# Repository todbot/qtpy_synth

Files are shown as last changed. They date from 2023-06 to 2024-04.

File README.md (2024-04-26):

# qtpy_synth

A simple [QTPy RP2040](https://learn.adafruit.com/adafruit-qt-py-2040/overview)-based
synth to experiment with [`synthio`](https://github.com/todbot/circuitpython-synthio-tricks).

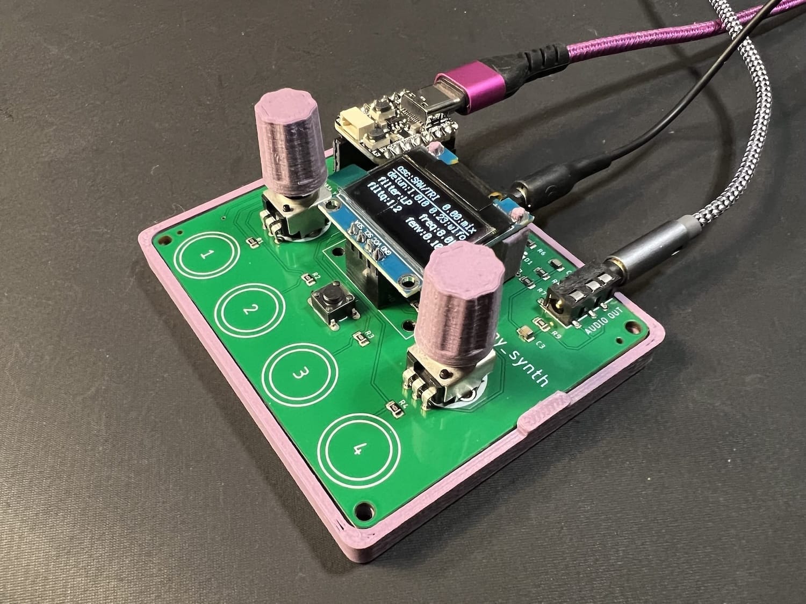
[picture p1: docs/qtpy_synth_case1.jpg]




### Features
 - Mono audio output circuit, converting PWM to audio, as per [RP2040 design guidelines](https://datasheets.raspberrypi.com/rp2040/hardware-design-with-rp2040.pdf#page=24)
 - Optoisolated MIDI Input via [MIDI TRS-A 3.5mm jack](https://www.perfectcircuit.com/make-noise-0-coast-midi-cable.html)
 - Two pots for controlling parameters
 - One switch for controlling parameters
 - Four capsense touch buttons for synth triggering
 - USB MIDI in/out of course too

### Software
Some programs written specifically for this board:

- [hwtest](./circuitpython/hwtest/code.py) - test out the hardware with a simple synth

- [simpletouchsynth](./circuitpython/simpletouchsynth) - play with filters using touch sensors. Uses intial cut at a "qtpy_synth" hardware library.

- [dronesynth](./circuitpython/dronesynth) - 8-oscillator drone synth

- [wavesynth](./circuitpython/wavesynth) - larger general two-osc synth that can also do wave-mixing and wavetables. Has many rough edges but can sound great!
  - early video demo:
  
    Wavetable synth w/ CircuitPython synthio on QTPy RP2040 (https://www.youtube.com/watch?v=4hgDi6MNfsI)]
  - another video demo:
  
    More Wavetable synth w/ CircuitPython synthio on QTPy RP2040 (https://www.youtube.com/watch?v=80yjwxscnnA)]

#### See also:
- https://github.com/todbot/circuitpython-synthio-tricks
  - Contains [many other synthio examples](https://github.com/todbot/circuitpython-synthio-tricks/tree/main/examples) that can work with this synth with minimal changes

### Building it

The [Tindie version is a partially-assembled PCB](https://www.tindie.com/products/todbot/qtpy_synth/). 

The completely assembled SMD sections of the board are:

* audio output circuit
* TRS MIDI input circuit

The parts you need to add are:

* [QTPy RP2040](https://www.adafruit.com/product/4900)
* 0.91" [I2C OLED display](https://amzn.to/3KDmy73) (w/ pins in Gnd/Vcc/SCL/SDA order)
* Two 10k potentiometers, 9mm  ([example pots](https://amzn.to/3DYYJm5)) and [knobs](https://amzn.to/3QAkSyR)
* One tact switch, 6mm ([example switch](https://amzn.to/47nJaSN))
* Headers and sockets to mount QTPy & display, to taste
  * [This male & female header kit looks pretty good](https://amzn.to/3qqbtiO),
    as I prefer to put female headers on the PCB and male headers on the QTPy and OLED display.
    You may need to trim down your headers to be the right size.
* Feet. I like M2.5 nylon standoffs  (e.g. [M2.5 standoff asst kit](https://amzn.to/45qVjFb))
  but feel free to do what you like, including making an enclosure!
* Or [3d-print a simple case](https://www.printables.com/model/757087-case-for-qtpy_synth-circuitpython-synthesizer) for it! I also like these [3d-printed knobs](https://www.thingiverse.com/thing:5759656)

### Pins used

The board uses all of the QTPy RP2040 pins:

* `board.A0` - left knob
* `board.A1` - right knob
* `board.TX` - middle button
* `board.RX` - TRS UART MIDI in
* `board.MOSI` - PWM Audio Out
* `board.SCL` & `board.SDA` - I2C bus for OLED display
* `board.A3`, `board.A2`, `board.MISO`, `board.SCK`,  -- touch pads 1,2,3,4

For more details see [`hwtest/code.py`](https://github.com/todbot/qtpy_synth/tree/main/circuitpython/hwtest/code.py).

### Schematic

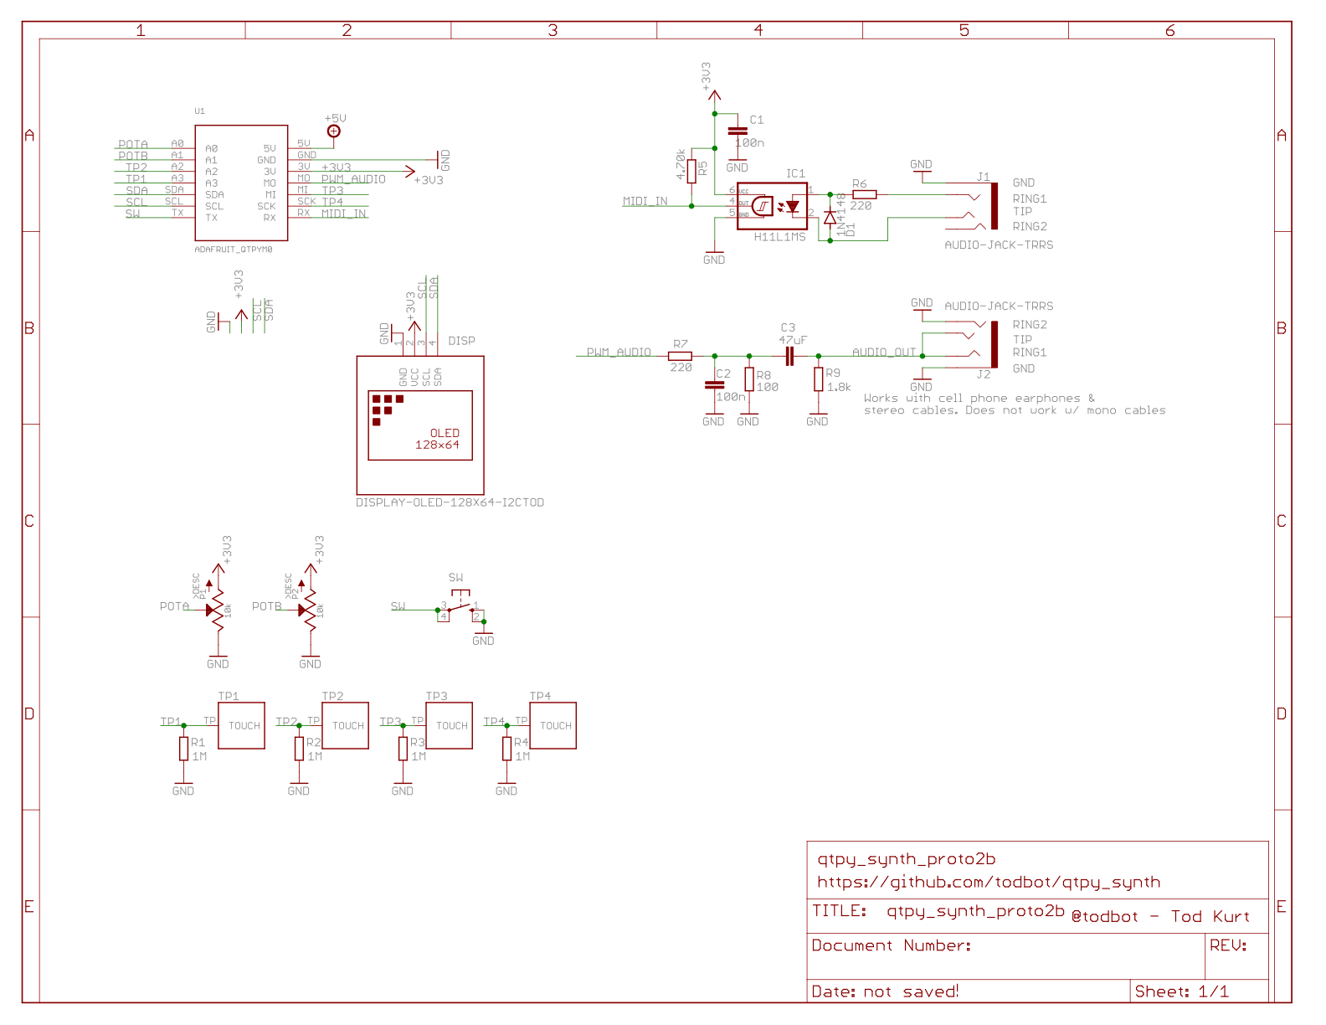
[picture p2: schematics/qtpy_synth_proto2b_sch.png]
[](./schematics/qtpy_synth_proto2b_sch.pdf)

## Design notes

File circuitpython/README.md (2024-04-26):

qtpy_synth circuitpython
========================

This is a collection of example synths to run on the qtpy_synth board.

These examples include:

- "[hwtest](./hwtest)" -- check that all hardware parts work
- "[simpletouchsynth](./simpletouchsynth)" -- very simple single-patch synth with adjustable filter
- "[wavesynth](./wavesynth)" -- wavetable synthesizer with GUI and wavetable selection

### Running the examples:

To run these examples:

1. Copy the contents of the `lib` here directory to CIRCUITPY/lib
2. Copy everything in example synth's directory to the CIRCUITPY drive 
     (e.g. `code.py` file and any other files)
3. Install external libraries. They are listed in `requirements.txt`.
    The easiest way to install them is with `circup` on the commandline:
    ```sh
    circup install -r requirements.txt
    ```

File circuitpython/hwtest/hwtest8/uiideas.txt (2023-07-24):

#
#
# UI Ideas:
#  - touch buttons
#    - press to trigger note
#    - hold to enable setting of button params, edit with potA, potB, sw
#      - what about holding multiple  (maybe do not allow)
#    - press hard for filter mod?
#  - pots
#    - if no button press, changes global param, like filter, res
#
#  - knob UI sets:
#
#    param sets
#    1. filter type + filter freq
#    2. osc detune + filter res
#    3. wave select (as below) + wave_mix
#    4. atk / rls
#
#    or:
#    1. wave select (saw/tri/wtb + fname) + wave_mix
#    2. osc detune + wave_mix_lfo
#    3a. filter type + filter freq
#    3b. filter res + filter_env_amount
#    4. atk / rls
#
#    x. osc/wtb e | wave saw/squ/tri
#       - waveA squ/tri/saw + wave_mix
#         (turning A goes : Asaw->None, Asaw->Bsqu, Asaw->Btri, Asqu->BNon, Asqu->Btri, Atri->None
#
#    x turn knobA choices:
#       - osc: A saw / B tri
#         osc: A saw / B squ
#         osc: A saw / B sin
#         osc: A squ / B tri
#         osc: A squ / B tri
#         wtb: wave filename1
#         wtb: wave filename2
#         wtb: wave filename3
#         wtb: wave filename4
#
#
#    x. wavetable + wave_mix_lfo
#
#    4. atk time / rls time
#
#  - sw
#    - toggles currently changeable pot params
#      - param set 1: freq & resonance
#      - param set 2: freq type (LP,HP,BP,BN) & osc detune spread
#      - param set 3: attack & release times
#      - param set 4: LFO1 rate & depth
#
# Arpeggiator?
#

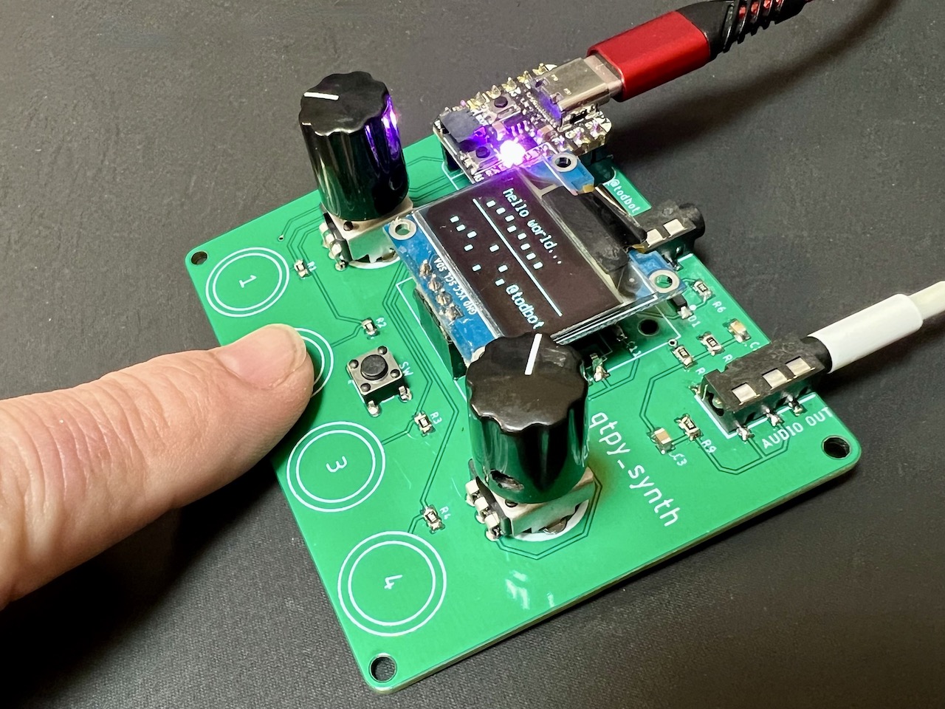
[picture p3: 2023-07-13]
docs/qtpy_synth_proto2a.jpg

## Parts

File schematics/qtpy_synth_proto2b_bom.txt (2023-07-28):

Qty	Value	Device	Package	Parts	Description	LCSC	MF MPN
1		10-XX	B3F-10XX	SW	OMRON SWITCH		B3F-1000
1	1.8k	R-EU_R0805	R0805	R9	"RESISTOR, European symbol"		
1	100	R-EU_R0805	R0805	R8	"RESISTOR, European symbol"		
2	100n	C-EUC0805	C0805	"C1, C2"	"CAPACITOR, European symbol"		
2	10k	POTZEPHPOT_BIGKNOB	OG-POTS_ALPS_POT_VERTICAL_WITHBIGKNOB	"P1, P2"			
4	1M	R-EU_R0805	R0805	"R1, R2, R3, R4"	"RESISTOR, European symbol"		
1	1N4148	DIODE-SOD123	SOD123	D1	DIODE		
2	220	R-EU_R0805	R0805	"R6, R7"	"RESISTOR, European symbol"		
1	4.70k	R-EU_R0805	R0805	R5	"RESISTOR, European symbol"		
1	47uF	C-EUC0805	C0805	C3	"CAPACITOR, European symbol"		
1	ADAFRUIT_QTPYM0	ADAFRUIT_QTPYM0	ADAFRUIT_QTPY_M0	U1			
2	AUDIO-JACK-TRRS	AUDIO-JACK-TRRS	PJ-320D_SPARKFUN	"J1, J2"		C431535	PJ-320D
1	DISPLAY-OLED-128X64-I2CTOD	DISPLAY-OLED-128X64-I2CTOD	DISPLAY-OLED-128X64-I2C-TOD	DISP	128x64 Dot Matrix OLED Module	based on SSD1306 chip	
1	H11L1MS	H11L1MS	DIL6-SMD	IC1	6-Pin DIP Optocoupler	C78589

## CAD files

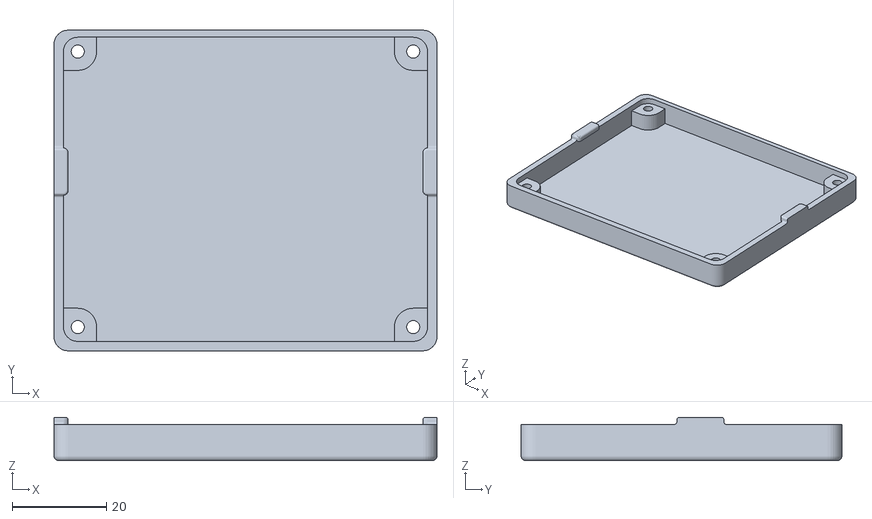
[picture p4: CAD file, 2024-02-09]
enclosure/qtpy_synth_case.stl
81.2 x 68.0 x 9.20

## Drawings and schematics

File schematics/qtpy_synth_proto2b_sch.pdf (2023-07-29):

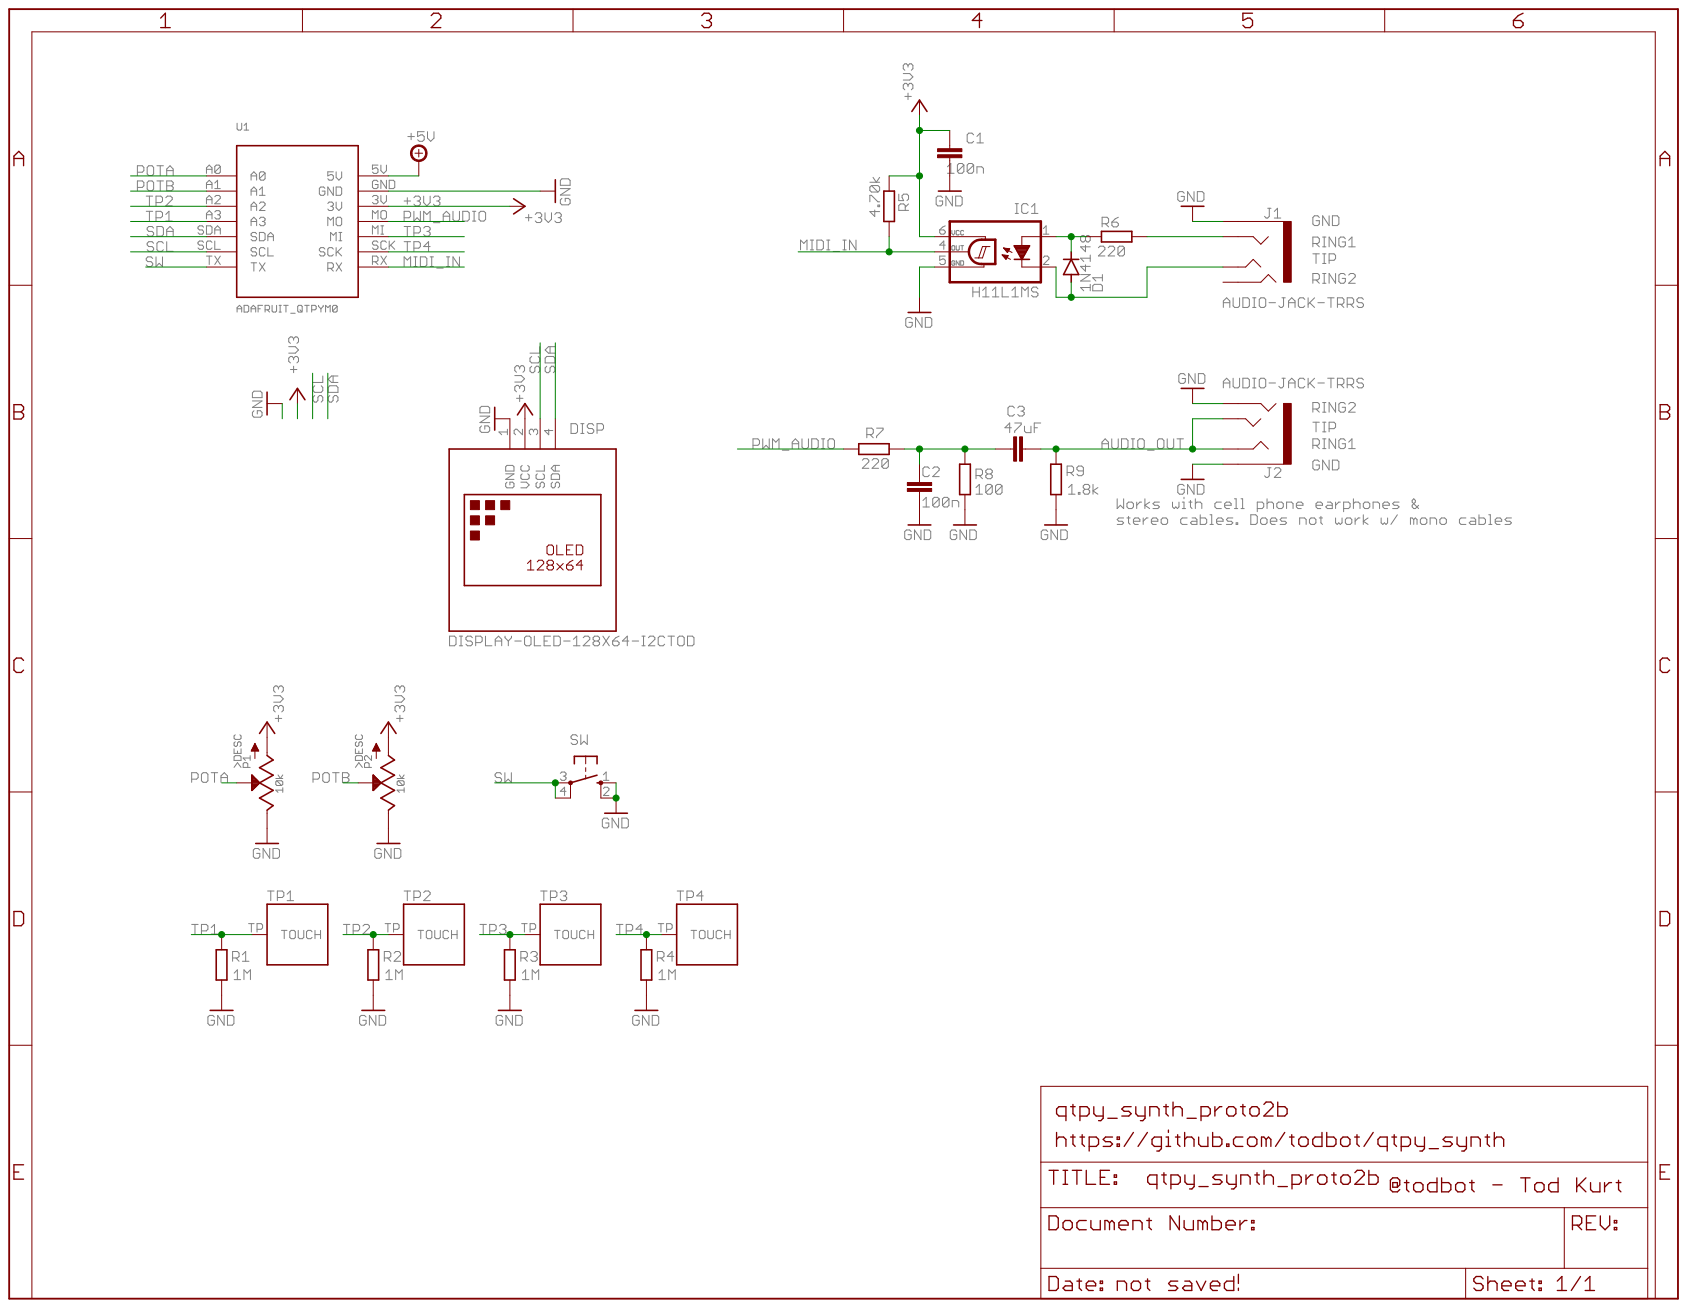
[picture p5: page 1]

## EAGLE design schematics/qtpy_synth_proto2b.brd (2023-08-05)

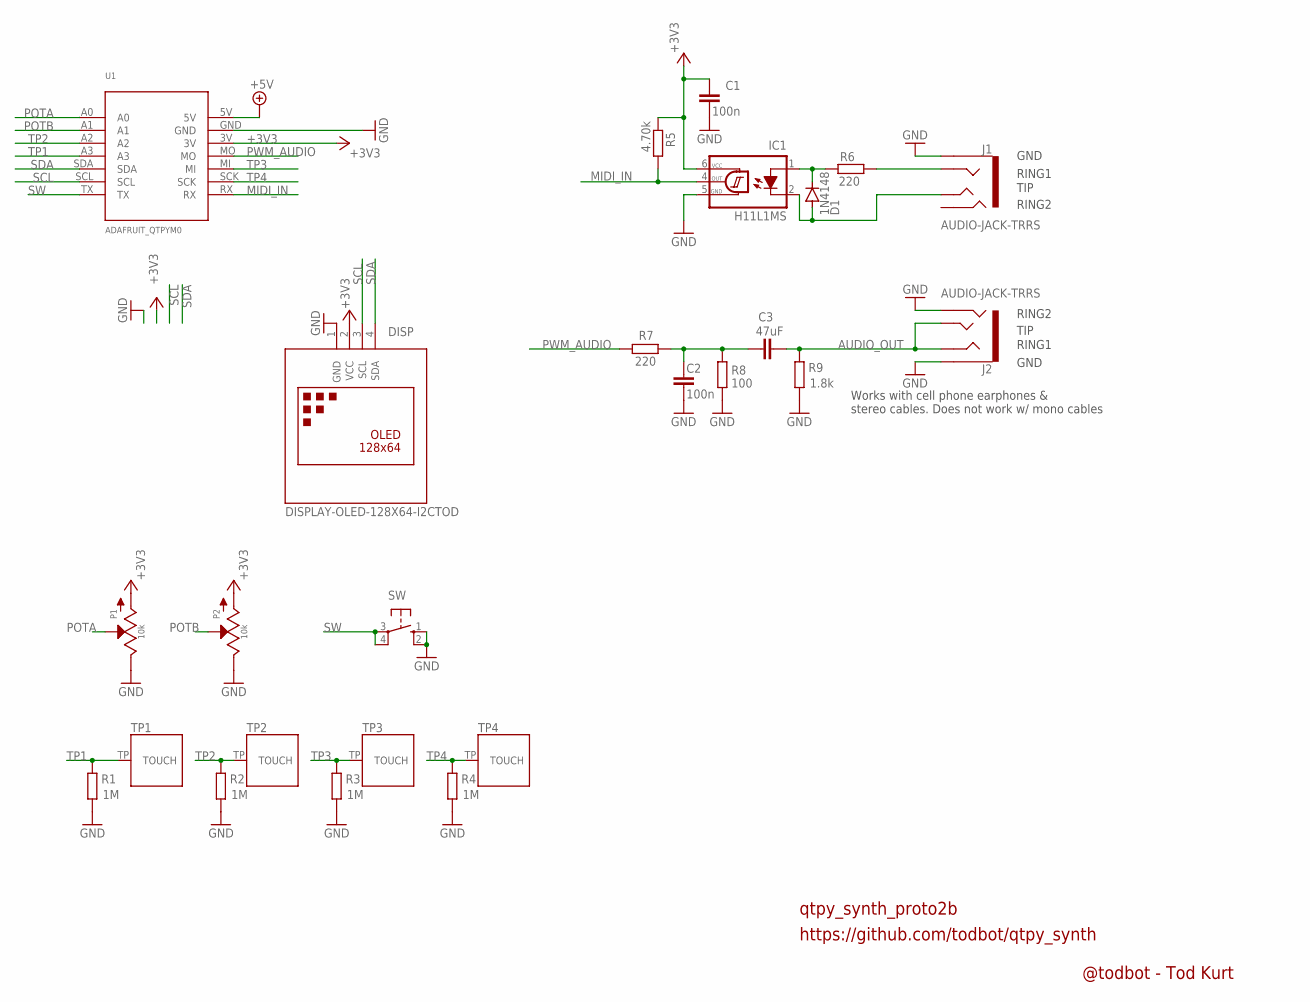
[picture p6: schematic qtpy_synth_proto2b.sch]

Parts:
C1, C2: 100n; C0805
C3: 47uF; C0805
D1: 1N4148; SOD123
DISP: DISPLAY-OLED-128X64-I2CTOD; DISPLAY-OLED-128X64-I2C-TOD
IC1: H11L1MS; DIL6-SMD; MPN2 H11L1S; LCSC C78589
J1: AUDIO-JACK-TRRS; PJ-320D_SPARKFUN
J2: AUDIO-JACK-TRRS; PJ-320D_SPARKFUN; LCSC C431535
P1, P2: 10k; OG-POTS_ALPS_POT_VERTICAL_WITHBIGKNOB
R1, R2, R3, R4: 1M; R0805
R5: 4.70k; R0805
R6, R7: 220; R0805
R8: 100; R0805
R9: 1.8k; R0805
SW: 10-XX; B3F-10XX
TP1, TP2, TP3, TP4: TOUCHPADA; TOUCHPADA_0.5IN
U1: ADAFRUIT_QTPYM0; ADAFRUIT_QTPY_M0

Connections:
+3V3: C1.1, DISP.2 (VCC), IC1.6 (VCC), P1.P$3 (A), P2.P$3 (A), R5.1, U1.3V
+5V: U1.5V
AUDIO_OUT: C3.2, J2.RING1, J2.TIP, R9.1
GND: C1.2, C2.2, DISP.1 (GND), IC1.5 (GND), J1.EARTH, J2.EARTH, J2.RING2, P1.P$1 (E), P2.P$1 (E), R1.2, R2.2, R3.2, R4.2, R8.1, R9.2, SW.1 (S), SW.2 (S1), U1.GND
MIDI_IN: IC1.4 (OUT), R5.2, U1.RX
unnamed: J1.RING1, R6.2
unnamed: D1.C, IC1.1 (A), R6.1
unnamed: D1.A, IC1.2 (C), J1.TIP
unnamed: C2.1, C3.1, R7.1, R8.2
POTA: P1.P$2 (S), U1.A0
POTB: P2.P$2 (S), U1.A1
PWM_AUDIO: R7.2, U1.MO
SCL: DISP.3 (SCL), U1.SCL
SDA: DISP.4 (SDA), U1.SDA
SW: SW.3, SW.4 (P1), U1.TX
TP1: R1.1, TP1.TP, U1.A3
TP2: R2.1, TP2.TP, U1.A2
TP3: R3.1, TP3.TP, U1.MI
TP4: R4.1, TP4.TP, U1.SCK

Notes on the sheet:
qtpy_synth_proto2b
https://github.com/todbot/qtpy_synth
RING2
RING1
GND
TIP
Works with cell phone earphones & stereo cables. Does not work w/ mono cables
@todbot - Tod Kurt

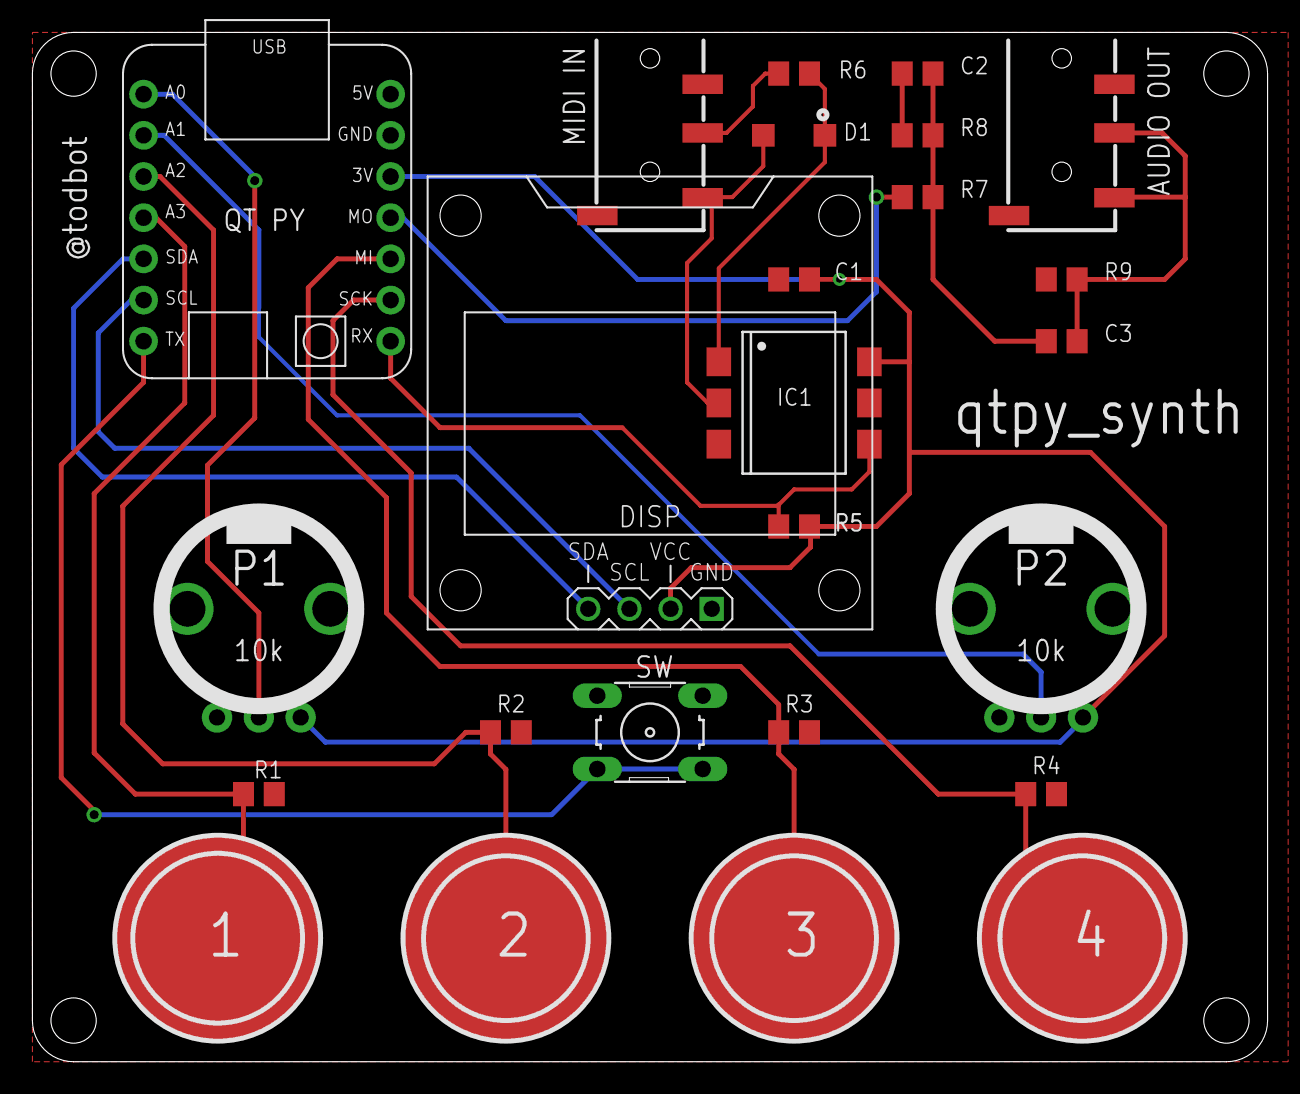
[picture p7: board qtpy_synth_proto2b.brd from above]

Board: 2 copper layers, 76.2 x 63.5 mm, 25 parts (0 on the bottom side), 18 nets.

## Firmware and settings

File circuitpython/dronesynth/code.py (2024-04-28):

# dronesynth_code.py -- drone synth for qtpy_synth
# 25 Apr 2024 - @todbot / Tod Kurt
# part of https://github.com/todbot/qtpy_synth
#
# Needed libraries to install:
#  circup install asyncio neopixel adafruit_debouncer adafruit_displayio_ssd1306 adafruit_display_text
# Also install "qtpy_synth" directory in CIRCUITPY/lib
#
# How to use:
#
# - This synth has four pair of oscillators (8 total)
# - Each pad controls an oscillator pad
# - While holding a pad:
#   - left pot A adjusts oscillator pair center frequency
#   - right pot B adjusts oscillator frequency "spread" / "detune"
#   - middle tact button mutes/unmutes the oscillator pair
#
#

import asyncio
import time
import random
import synthio
import usb_midi

import displayio, terminalio, vectorio
from adafruit_display_text import bitmap_label as label

from qtpy_synth.hardware import Hardware

from param_scaler import ParamScaler
from my_little_droney import (MyLittleDroney, SynthConfig,
                              get_freqs_by_knobs, note_to_knobval, knobval_to_note)

import microcontroller
microcontroller.cpu.frequency = 250_000_000  # overclock! vrrroomm

num_pads = 4
oscs_per_pad = 2
note_offset = 12
note_range = 60
initial_vals = (note_to_knobval(36), note_to_knobval(48),
                note_to_knobval(36), note_to_knobval(60))

qts = Hardware()
cfg = SynthConfig()

droney = MyLittleDroney(qts.synth, cfg, num_pads, oscs_per_pad) #, initial_notes)

pad_num = None  # which pad is currently being touched
voice_vals = []  # scaled knob vals per pad, index = pad number, val = [valA,valB]
button_held = False
button_held_time = 0

# -----------------------------

# set up display with our chunks of info
disp_group = displayio.Group()
qts.display.root_group = disp_group
labels_pos = ( (5,5), (45,5),
               (5,18), (45,18),
               (5,30), (45,30),
               (5,42), (45,42),
               (78,5), (78,18), (78,30), (78,42),
               (115,5) # dronesynth logo vertical
              ) 
disp_info = displayio.Group()
for (x,y) in labels_pos:
    disp_info.append( label.Label(terminalio.FONT, text="--", x=x, y=y) )
disp_group.append(disp_info)
disp_info[-1].text = "dronesynth"
disp_info[-1].label_direction = "UPR"

def display_update():
    for i in range(num_pads):
        fstr = disp_info[i*2+0].text
        dstr = disp_info[i*2+1].text
        fstr_new = "%.1f" % knobval_to_note(voice_vals[i][0], note_offset, note_range)
        dstr_new = "%.1f" % voice_vals[i][1]
        if fstr_new != fstr:
            disp_info[i*2+0].text = fstr_new
        if dstr_new != dstr:
            disp_info[i*2+1].text = dstr_new
        onoff = "on" if droney.voices[i][0].amplitude else "--"
        if disp_info[8+i].text != onoff:
            disp_info[8+i].text = onoff


# --------------------------------------------------------

# get initial knob vals for the scalers
(knobA_val, knobB_val) = [v/256 for v in qts.read_pots()]

# set up the inital state of the voices
for i in range(num_pads):
    vs = [initial_vals[i], 0]
    voice_vals.append(vs)
    
    # set up default freqs in droney
    freqs = get_freqs_by_knobs(vs[0],vs[1], note_offset, note_range)
    print("freqs:", freqs)
    droney.set_voice_freqs(i, freqs)

# start with only two of the voices sounding
droney.toggle_voice_mute(2)
droney.toggle_voice_mute(3)

scalerA = ParamScaler(voice_vals[0][0], knobA_val)
scalerB = ParamScaler(voice_vals[0][1], knobB_val)

globalA_val = knobA_val
globalB_val = knobB_val

display_update()

debug = False
def dbg(*args,**kwargs):
    if debug: print(*args,**kwargs)

while True:
    time.sleep(0.001)

    #droney.update()
    
    (knobA_val, knobB_val) = [v/256 for v in qts.read_pots()]
    
    # handle held touch pad
    if pad_num is not None: 
        
        valA = scalerA.update(knobA_val) #, debug=True)
        valB = scalerB.update(knobB_val)
        
        dbg("knobA:%.1f knobB:%.1f  valA:%.1f  valB:%.1f" %
            (knobA_val, knobB_val, valA, valB))

        freqs = get_freqs_by_knobs(valA, valB, note_offset, note_range)
        droney.set_voice_freqs(pad_num, freqs)

        voice_vals[touch.key_number] = [valA,valB]
        display_update()
        
    else:
        globalA_val = scalerA.update(knobA_val)
        globalB_val = scalerB.update(knobB_val) # , debug=True)
        #dbg("global: %1.f %1.f" %(globalA_val, globalB_val))
        #droney.set_pitch_lfo_amount(knobB_val/255)
        #note_offset = (globalA_val/255) * 24
        f = 20 + (globalA_val/255) * 3000
        droney.set_filter(f,None)

    # handle pad press
    if touches := qts.check_touch():
        for touch in touches:
            
            if touch.pressed:
                pad_num = touch.key_number
                # restore vals for this pad 
                lastA, lastB = voice_vals[pad_num]  
                scalerA.reset(lastA, knobA_val)
                scalerB.reset(lastB, knobB_val)

            if touch.released:
                pad_num = None
                # restore the global vals
                scalerA.reset(globalA_val, knobA_val)
                scalerB.reset(globalB_val, knobB_val)

    # handle tact button press
    if key := qts.check_key():
        if key.pressed:
            print("button!")
            button_held = True
            button_held_time = time.monotonic()
            droney.print_freqs()
            if pad_num is not None: # pressing a pad toggles voice
                droney.toggle_voice_mute(pad_num)

            
        if key.released:
            button_held = False

    # handle button held 
    button_time_delta = time.monotonic() - button_held_time
    if button_held and button_time_delta > 1:
        dbg("drone freqs")
        for i,vs in enumerate(voice_vals):
            dbg("%d: " % i, end='')
            for v in vs:
               dbg("%.2f, " % v, end='')
            dbg()


        # if button is held, convert the notes to pad1 note
        converge_valA, converge_valB = voice_vals[0]
        cff = 0.05
        for i in range(1,num_pads):
            voice_vals[i][0] = cff*converge_valA + (1-cff)*voice_vals[i][0]
            freqs = get_freqs_by_knobs(voice_vals[i][0], voice_vals[i][1], note_offset, note_range)
            droney.set_voice_freqs(i, freqs)
            display_update()
            
            





                

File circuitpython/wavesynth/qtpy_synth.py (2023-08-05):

# qtpy_synth.py -- hardware defines and setup for qtpy_synth board
# 22 Jul 2023 - @todbot / Tod Kurt
# part of https://github.com/todbot/qtpy_synth
#
# libraries needed:
#  circup install neopixel, adafruit_debouncer, adafruit_displayio_ssd1306
#
# UI fixme:
# knob "pickup" vs knob "catchup"  (maybe done in app instead)

import board, busio
import analogio, keypad
import touchio
from adafruit_debouncer import Debouncer
import neopixel
import audiopwmio, audiomixer
import synthio
import displayio
import adafruit_displayio_ssd1306

SAMPLE_RATE = 25600   # lets try powers of two
MIXER_BUFFER_SIZE = 4096
DW,DH = 128, 64  # display width/height

# note: we're hanging on to some of the interstitial objects like 'i2c' & 'display_bus'
# even though we shouldn't, because I think the gc will collect it unless we hold on to it

class QTPySynthHardware():
    def __init__(self):

        self.led = neopixel.NeoPixel(board.NEOPIXEL, 1, brightness=0.1)
        self.keys = keypad.Keys( pins=(board.TX,),  value_when_pressed=False )
        self._knobA = analogio.AnalogIn(board.A0)
        self._knobB = analogio.AnalogIn(board.A1)
        self.knobA = self._knobA.value
        self.knobB = self._knobB.value

        self.touchins = []  # for raw_value
        self.touches = []   # for debouncer
        for pin in (board.A3, board.A2, board.MISO, board.SCK):
           touchin = touchio.TouchIn(pin)
           # touchin.threshold = int(touchin.threshold * 1.1) # noise protection
           self.touchins.append(touchin)
           self.touches.append( Debouncer(touchin) )

        self.midi_uart = busio.UART(rx=board.RX, baudrate=31250, timeout=0.001)

        displayio.release_displays()
        i2c = busio.I2C(scl=board.SCL, sda=board.SDA, frequency=400_000 )
        display_bus = displayio.I2CDisplay(i2c, device_address=0x3c )
        self.display = adafruit_displayio_ssd1306.SSD1306(display_bus, width=DW, height=DH, rotation=180)

        # now do audio setup so we have minimal audible glitches
        self.audio = audiopwmio.PWMAudioOut(board.MOSI)
        self.mixer = audiomixer.Mixer(sample_rate=SAMPLE_RATE, voice_count=1, channel_count=1,
                                     bits_per_sample=16, samples_signed=True,
                                     buffer_size=MIXER_BUFFER_SIZE)
        self.synth = synthio.Synthesizer(sample_rate=SAMPLE_RATE)
        self.audio.play(self.mixer)
        self.mixer.voice[0].play(self.synth)

    def check_key(self):
        return self.keys.events.get()

    def read_pots(self):
        """Read the knobs, filter out their noise """
        filt = 0.5

        # avg_cnt = 5
        # knobA_vals = [self.knobA] * avg_cnt
        # knobB_vals = [self.knobB] * avg_cnt
        # for i in range(avg_cnt):
        #     knobA_vals[i] = self._knobA.value
        #     knobB_vals[i] = self._knobB.value

        # self.knobA = filt * self.knobA + (1-filt)*(sum(knobA_vals)/avg_cnt)  # filter noise
        # self.knobB = filt * self.knobB + (1-filt)*(sum(knobB_vals)/avg_cnt)  # filter noise

        self.knobA = filt * self.knobA + (1-filt)*(self._knobA.value)  # filter noise
        self.knobB = filt * self.knobB + (1-filt)*(self._knobB.value)  # filter noise
        return (int(self.knobA), int(self.knobB))

    def check_touch(self):
        """Check the four touch inputs, return keypad-like Events"""
        events = []
        for i in 0,1,2,3:
            touch = self.touches[i]
            touch.update()
            if touch.rose:
                events.append(keypad.Event(i,True))
            elif touch.fell:
                events.append(keypad.Event(i,False))
        return events

    def check_touch_hold(self, hold_func):
        for i in 0,1,2,3:
            if self.touches[i].value:  # pressed
                v = self.touchins[i].raw_value - self.touchins[i].threshold
                hold_func(i, v)

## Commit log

2023-06-28 fix name, add hwtest
    [qtpy_synth_proto2a.brd, qtpy_synth_proto2a.sch]
2023-07-12 sync up
    [qtpy_synth_proto2b.brd, qtpy_synth_proto2b.sch]
2023-07-17 more progress on synthio_instrument
    [qtpy_synth_proto2b.brd]
2023-07-23 waveetable: getting out-of-memory when switching patches when in_memory=True, so just default to False for now
2023-07-28 gerbers for proto2b
    [qtpy_synth_proto2b.brd]
2023-07-28 added proto2b bom
2023-08-04 fix oled holes
    [qtpy_synth_proto2b.brd, qtpy_synth_proto2b.sch]
2023-08-04 added 4th config line to display, not working right yet
    [code.py, qtpy_synth.py, synthio_instrument.py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]
2023-08-05 cleanup proto2b pcb before fab submit
    [qtpy_synth_proto2b.brd]
2023-08-05 cleanup gerbers
2023-08-11 link to trs-a cable and hwtest script
2024-02-07 update hwtest to use smolmidi and make noise on midi receive
    [code.py, qtpy_synth.py]
2024-02-09 added 3d case

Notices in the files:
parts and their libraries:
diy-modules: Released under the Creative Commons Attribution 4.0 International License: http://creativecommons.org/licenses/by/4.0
